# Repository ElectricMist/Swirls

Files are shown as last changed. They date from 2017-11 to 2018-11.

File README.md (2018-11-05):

PCBs and Front panels Available at Pusherman at a fair price :
https://pushermanproductions.com/product/swirls-lamb-8hp-tides-sheep-black-fr4-reversible-panel-pcb-set/

Swirls is a 8HP version of Mutable Instruments Tides

- PCB v1.0 is tested and working
  known issues :
  side holes for the trimmers are too small,
  Silkscreen Mistake (C26 & R27 are flipped)
  
- PCB V1.1 
  the errors of v1.0 are fixed
  
The front panel is double Side
  - One side for Swirls (running the Tides firmware)
  - One side for Lamb (running the Sheep firmware)

Please if you are planning to sell some pcbs and panels, contact me first.

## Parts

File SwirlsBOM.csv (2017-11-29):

SWIRLS V1.0
Index | Qty | Description | Specs | Value | Package | Ref. Mouser | References
SMT parts
R2, R3, R4, R7, R9, R10, R22, R24 | 8 | Resistor, 1% |  | 100 | 0603 | 652-CR0603FX-1000ELF
R27 | 1 | Resistor, 1% |  | 270 | 0603 | 652-CR0603FX-2700ELF
R8 | 1 | Resistor, 1% |  | 2.49k | 0603 | 652-CR0603FX-2491ELF
R60 | 1 | Resistor, 1% |  | 2.49k | 0805 | 652-CR0805FX-2491ELF
R12, R50, R52 | 3 | Resistor, 1% |  | 3.3k | 0603 | 652-CR0603-FX3301ELF
R51, R53 | 2 | Resistor, 1% |  | 4.7k | 0603 | 652-CR0603FX-4701ELF
R47, R48, R49, R57, R58 | 5 | Resistor, 1% |  | 10k | 0603 | 652-CR0603-FX-1002GLF
R34 | 1 | Resistor, 1% |  | 20k | 0603 | 652-CR0603FX-2002ELF
R37 | 1 | Resistor, 1% |  | 27k | 0603 | 652-CR0603FX-2702ELF
R20 | 1 | Resistor, 1% |  | 30k | 0603 | 652-CR0603FX-3002ELF
R13, R15, R28, R33, R40 | 5 | Resistor, 1% |  | 33k | 0603 | 652-CR0603FX-3302ELF
R45 | 1 | Resistor, 1% |  | 39k | 0603 | 652-CR0603FX-3902ELF
R14, R16, R26, R29, R30, R31, R32, R36, R38, R39, R41, R42, R44, R54, R55, R56 | 16 | Resistor, 1% |  | 100k | 0603 | 652-CR0603-FX-1003GLF
R23, R35, R43 | 3 | Resistor, 1% |  | 120k | 0603 | 652-CR0603FX-1203ELF
R21, R25 | 2 | Resistor, 1% |  | 220k | 0603 | 652-CR0603FX-2203ELF
R46 | 1 | Resistor, 1% |  | 3.3M | 0603 | 71-CRCW06033M30FKEA
C2, C17 | 2 | Capacitor, ceramic |  | 18p | 0603 | 81-GRM185C1H180JA01J
C19, C21, C22, C23 | 4 | Capacitor, ceramic | >= 16V, <= 2%, C0G | 220p | 0603 | 81-GRM185C1H221GA01D
C27, C31, C34 | 3 | Capacitor, ceramic | >= 50V, <= 2%, C0G | 1n | 0603 | 81-GRM1885C1H102FA1J
C28, C29, C32 | 3 | Capacitor, ceramic | >= 50V, <= 5% | 10n | 0603 | 81-GRM18R71H103JA01D
C4, C5, C6, C7, C12, C14, C16, C18, C20, C24, C25, C30, C33 | 13 | Capacitor, ceramic | >= 16V | 100n | 0603 | 81-GRM188R71E104JA1J
C13, C26 | 2 | Capacitor, ceramic | >= 16V | 470n | 0603 | 81-GRM18F51C474ZA01J
C11, C15 | 2 | Capacitor, ceramic | >= 6.3V | 3.3u | 0603 | 81-GRM188R61A335KE5D
C1, C8, C9 | 3 | Capacitor, electrolytic | >= 25V | 22u | Panasonic C | 667-EEE-FP1E220AR | EEE-FP1E220AR
C3, C10 | 2 | Capacitor, electrolytic | >= 25V | 47u | Panasonic D | 667-EEE-FK1V470P | EEEFK1V470P
D1, D2 | 2 | 1N5819HW diode |  |  | SOD123 | 621-1N5819HW-F | Diodes Inc 1N5819HW-7-F
IC1, IC3 | 2 | LM1117-3.3V LDO Vreg |  | 3.3V | SO223 | 926-LM1117MPX3.3NOPB | National LM1117MPX3.3NOPB
IC2 | 1 | LM4040 Shunt Vref | A, B or C grade | 2.5V | SOT23 | 595-LM4040C25IDBZR | Texas Instruments LM4040C25IDBZ
IC7 | 1 | LM4040 Shunt Vref | A, B or C grade | 10V | SOT23 | 595-LM4040C10IDBZR | Texas Instruments LM4040C10IDBZ
IC4 | 1 | DAC8552 dual 16-bit DAC |  |  | MSOP8 | 595-DAC8552IDGKT | Texas Instruments DAC8552IDGKT
IC5, IC6 | 2 | TL072 dual op-amp |  |  | TSSOP-8 | 595-TL072CPWR | TI TL072CPWR
IC8 | 1 | MCP6002 dual op-amp R2R IO |  |  | SOIC8 | 579-MCP6002-I/SN | MCP6002-I/SN
IC9 | 1 | MCP6004 dual op-amp R2R IO |  |  | TSSOP-14 | 579-MCP6004-I/ST | MCP6004-I/ST
Q2, Q3, Q4, Q5, Q6 | 5 | NPN transistor MMBT3904 |  |  | SOT23 | 863-MMBT3904LT1G | On Semi MMBT3904LT1G
Q1 | 1 | 8 MHz quartz |  |  | HC49 | 815-ABLS2-8-D4Y-T | Abracon ABLS2-8.000MHZ-D4Y-T
UC1 | 1 | STM32F103CBT6 MCU |  |  | LQFP48 | 511-STM32F103CBT6 | ST STM32F103CBT6
TH parts |  | MFG Part No:D6R90 F1 LFS
J1, J2, J3, J4, J5, J6, J7, J8, J9, J10, J11, J12, J13 | 13 | Vertical jack connector |  |  |  |  | PJ-301-M-12
LED1, LED2, LED3 | 3 | LED, Red/Green, 3 terminals, common K |  |  | 3 terminals | 604-WP115VEGW | Kingbright WP115VEGW
SW3, SW4 | 2 | Push-button 6.0X2.8MM |  |  |  | 612-TL1105SP-250 | E-switch TL1105SPF250Q
 | 2 | Push-button caps |  |  |  | 612-1R-BK | E-switch 1RBLK
R5 | 1 | 10k linear pot, 15mm shaft |  |  |  |  | https://www.thonk.co.uk/shop/alpha-9mm-pots/
R6, R17, R18, R19 | 4 | 10k linear Tall Trimmer |  |  |  |  | https://www.thonk.co.uk/shop/ttpots/
R59 | 1 | 50k Trimmer resistor, 25 turns, top adjust. |  | 50k |  | 652-3296W-1-503LF | 3296W-1-503LF
JP1 | 1 | 2x5 male header, 2.54mm pitch |  |  |  | 649-67996-410HLF
JP2 | 1 | 2x5, 1.27mm pitch male header |  |  |  | 649-221111-00010T4LF

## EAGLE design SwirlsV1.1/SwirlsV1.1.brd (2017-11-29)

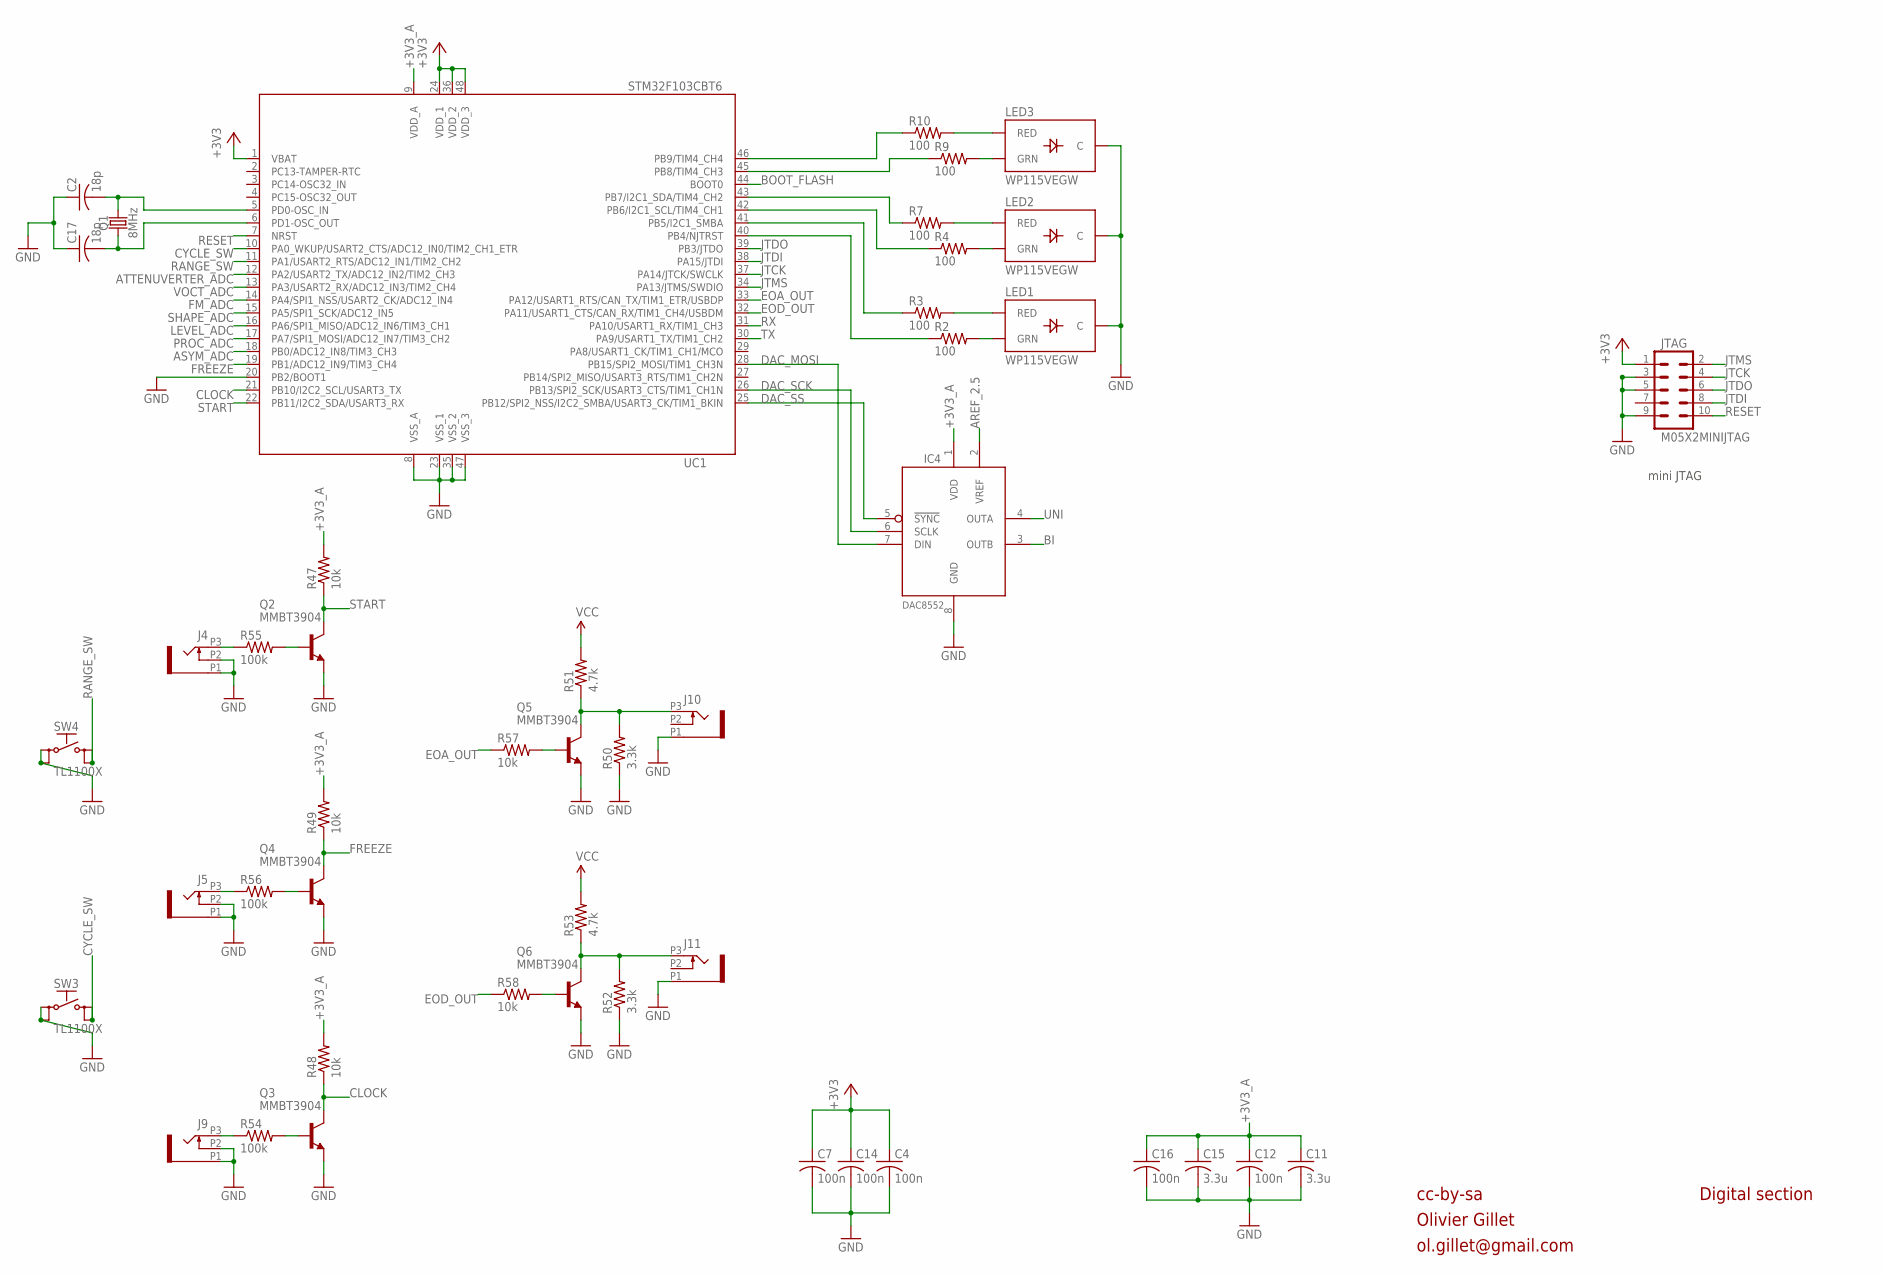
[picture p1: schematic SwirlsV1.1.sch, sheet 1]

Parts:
C2, C17: 18p; C0603
C4, C7, C12, C14, C16: 100n; C0603
C11, C15: 3.3u; C0603
IC4: DAC8552; MSOP-8
J4, J5, J9, J10, J11: PJ301_GUI6; OG-PJ301_VARIATIONS_WQP_PJ_301M6
JTAG: M05X2MINIJTAG; 2X5-1.27
LED1, LED2, LED3: WP115VEGW; LED-BICOLOR-THROUGHHOLE
Q1: 8MHz; HC49UP
Q2, Q3, Q4, Q5, Q6: MMBT3904; SOT23-BEC
R2, R3, R4, R7, R9, R10: 100; R0603
R47, R48, R49, R57, R58: 10k; R0603
R50, R52: 3.3k; R0603
R51, R53: 4.7k; R0603
R54, R55, R56: 100k; R0603
SW3, SW4: TL1100X
UC1: STM32F103CBT6; LQFP48

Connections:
+3V3: C4.1, C7.1, C14.1, JTAG.1, UC1.1 (VBAT), UC1.24 (VDD_1), UC1.36 (VDD_2), UC1.48 (VDD_3); also elsewhere on the board
+3V3_A: C11.1, C12.1, C15.1, C16.1, IC4.1 (VDD), R47.2, R48.2, R49.2, UC1.9 (VDD_A); also elsewhere on the board
AREF_2.5: IC4.2 (VREF); also elsewhere on the board
ASYM_ADC: UC1.18 (PB0/ADC12_IN8/TIM3_CH3); also elsewhere on the board
ATTENUVERTER_ADC: UC1.12 (PA2/USART2_TX/ADC12_IN2/TIM2_CH3); also elsewhere on the board
BI: IC4.3 (OUTB); also elsewhere on the board
BOOT_FLASH: UC1.44 (BOOT0)
CLOCK: Q3.C, R48.1, UC1.21 (PB10/I2C2_SCL/USART3_TX)
CYCLE_SW: SW3.3 (S), SW3.4 (S1), UC1.10 (PA0_WKUP/USART2_CTS/ADC12_IN0/TIM2_CH1_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)
DAC_MOSI: IC4.7 (DIN), UC1.28 (PB15/SPI2_MOSI/TIM1_CH3N)
DAC_SCK: IC4.6 (SCLK), UC1.26 (PB13/SPI2_SCK/USART3_CTS/TIM1_CH1N)
DAC_SS: IC4.5 (!SYNC), UC1.25 (PB12/SPI2_NSS/I2C2_SMBA/USART3_CK/TIM1_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)
EOA_OUT: R57.1, UC1.33 (PA12/USART1_RTS/CAN_TX/TIM1_ETR/USBDP)
EOD_OUT: R58.1, UC1.32 (PA11/USART1_CTS/CAN_RX/TIM1_CH4/USBDM)
FM_ADC: UC1.14 (PA4/SPI1_NSS/USART2_CK/ADC12_IN4); also elsewhere on the board
FREEZE: Q4.C, R49.1, UC1.19 (PB1/ADC12_IN9/TIM3_CH4)
GND: C2.1, C4.2, C7.2, C11.2, C12.2, C14.2, C15.2, C16.2, C17.1, IC4.8 (GND), J4.P1 (1), J4.P2 (2), J5.P1 (1), J5.P2 (2), J9.P1 (1), J9.P2 (2), J10.P1 (1), J11.P1 (1), JTAG.3, JTAG.5, JTAG.9, LED1.2 (C), LED2.2 (C), LED3.2 (C), Q2.E, Q3.E, Q4.E, Q5.E, Q6.E, R50.1, R52.1, SW3.1, SW3.2 (P1), SW4.1, SW4.2 (P1), UC1.8 (VSS_A), UC1.20 (PB2/BOOT1), UC1.23 (VSS_1), UC1.35 (VSS_2), UC1.47 (VSS_3); also elsewhere on the board
JTCK: JTAG.4, UC1.37 (PA14/JTCK/SWCLK)
JTDI: JTAG.8, UC1.38 (PA15/JTDI)
JTDO: JTAG.6, UC1.39 (PB3/JTDO)
JTMS: JTAG.2, UC1.34 (PA13/JTMS/SWDIO)
LEVEL_ADC: UC1.16 (PA6/SPI1_MISO/ADC12_IN6/TIM3_CH1); also elsewhere on the board
unnamed: C2.2, Q1.2, UC1.5 (PD0-OSC_IN)
unnamed: C17.2, Q1.1, UC1.6 (PD1-OSC_OUT)
unnamed: J5.P3 (3), R56.1
unnamed: Q4.B, R56.2
unnamed: J9.P3 (3), R54.1
unnamed: Q3.B, R54.2
unnamed: Q6.B, R58.2
unnamed: J11.P3 (3), Q6.C, R52.2, R53.1
unnamed: LED3.3 (RED), R10.2
unnamed: LED3.1 (GRN), R9.2
unnamed: LED2.3 (RED), R7.2
unnamed: LED2.1 (GRN), R4.2
unnamed: LED1.3 (RED), R3.2
unnamed: LED1.1 (GRN), R2.2
unnamed: R10.1, UC1.46 (PB9/TIM4_CH4)
unnamed: R9.1, UC1.45 (PB8/TIM4_CH3)
unnamed: R7.1, UC1.43 (PB7/I2C1_SDA/TIM4_CH2)
unnamed: R4.1, UC1.42 (PB6/I2C1_SCL/TIM4_CH1)
unnamed: R3.1, UC1.41 (PB5/I2C1_SMBA)
unnamed: R2.1, UC1.40 (PB4/NJTRST)
unnamed: J10.P3 (3), Q5.C, R50.2, R51.1
unnamed: Q5.B, R57.2
unnamed: J4.P3 (3), R55.1
unnamed: Q2.B, R55.2
PROC_ADC: UC1.17 (PA7/SPI1_MOSI/ADC12_IN7/TIM3_CH2); also elsewhere on the board
RANGE_SW: SW4.3 (S), SW4.4 (S1), UC1.11 (PA1/USART2_RTS/ADC12_IN1/TIM2_CH2)
RESET: JTAG.10, UC1.7 (NRST)
RX: UC1.31 (PA10/USART1_RX/TIM1_CH3)
SHAPE_ADC: UC1.15 (PA5/SPI1_SCK/ADC12_IN5); also elsewhere on the board
START: Q2.C, R47.1, UC1.22 (PB11/I2C2_SDA/USART3_RX)
TX: UC1.30 (PA9/USART1_TX/TIM1_CH2)
UNI: IC4.4 (OUTA); also elsewhere on the board
VCC: R51.2, R53.2; also elsewhere on the board
VOCT_ADC: UC1.13 (PA3/USART2_RX/ADC12_IN3/TIM2_CH4); also elsewhere on the board

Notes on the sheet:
cc-by-sa
Olivier Gillet
ol.gillet@gmail.com
Digital section
mini JTAG

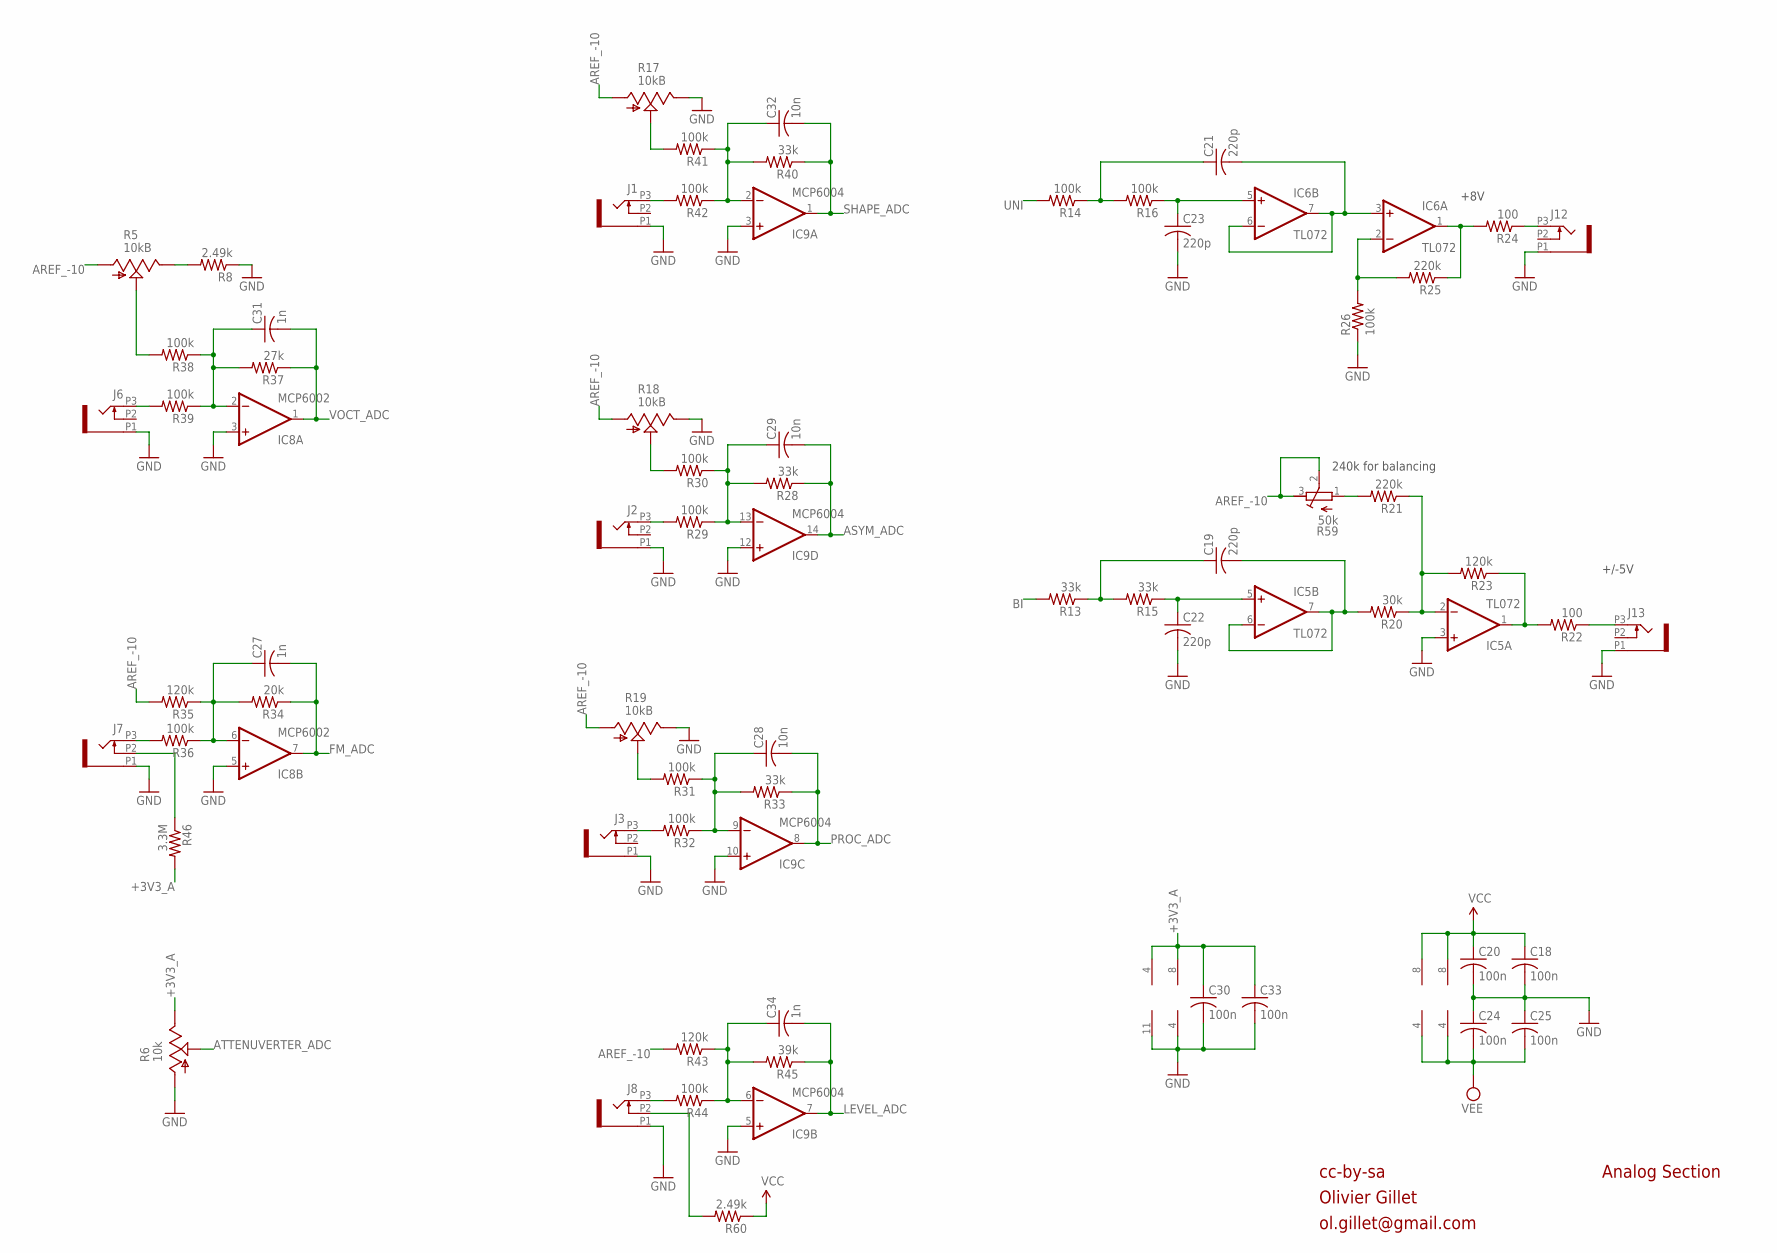
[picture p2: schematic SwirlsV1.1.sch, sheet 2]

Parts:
C18, C20, C24, C25, C30, C33: 100n; C0603
C19, C21, C22, C23: 220p; C0603
C27, C31, C34: 1n; C0603
C28, C29, C32: 10n; C0603
IC5, IC6: TL072; TSSOP-8
IC8: MCP6002; SO08
IC9: MCP6004; TSSOP14
J1, J2, J3, J6, J7, J8, J12, J13: PJ301_GUI6; OG-PJ301_VARIATIONS_WQP_PJ_301M6
R5: 10kB; ALPS_POT_VERTICAL_PS
R6: 10k; TALLTRIMMER
R8: 2.49k; R0603
R13, R15, R28, R33, R40: 33k; R0603
R14, R16, R26, R29, R30, R31, R32, R36, R38, R39, R41, R42, R44: 100k; R0603
R17, R18, R19: 10kB; TALLTRIMMER
R20: 30k; R0603
R21, R25: 220k; R0603
R22, R24: 100; R0603
R23, R35, R43: 120k; R0603
R34: 20k; R0603
R37: 27k; R0603
R45: 39k; R0603
R46: 3.3M; R0603
R59: 50k; RTRIM3296W
R60: 2.49k; R0805

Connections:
+3V3_A: C30.1, C33.1, IC8.8 (V+), IC9.4 (V+), R6.P$1 (E), R46.2; also elsewhere on the board
AREF_-10: R5.P$3 (A), R17.P$3 (A), R18.P$3 (A), R19.P$3 (A), R35.2, R43.2, R59.2 (S), R59.3 (E); also elsewhere on the board
ASYM_ADC: C29.2, IC9.14 (OUT), R28.1; also elsewhere on the board
ATTENUVERTER_ADC: R6.P$2 (S); also elsewhere on the board
BI: R13.2; also elsewhere on the board
BI_OUT: IC5.1 (OUT), R22.2, R23.1
FM_ADC: C27.2, IC8.7 (OUT), R34.1; also elsewhere on the board
F_CV: IC5.2 (-IN), R20.1, R21.1, R23.2
GND: C18.2, C20.2, C22.2, C23.2, C24.1, C25.1, C30.2, C33.2, IC5.3 (+IN), IC8.3 (+IN), IC8.4 (V-), IC8.5 (+IN), IC9.3 (+IN), IC9.5 (+IN), IC9.10 (+IN), IC9.11 (V-), IC9.12 (+IN), J1.P1 (1), J2.P1 (1), J3.P1 (1), J6.P1 (1), J7.P1 (1), J8.P1 (1), J12.P1 (1), J13.P1 (1), R6.P$3 (A), R8.1, R17.P$1 (E), R18.P$1 (E), R19.P$1 (E), R26.1; also elsewhere on the board
LEVEL_ADC: C34.2, IC9.7 (OUT), R45.1; also elsewhere on the board
unnamed: J1.P3 (3), R42.2
unnamed: C32.1, IC9.2 (-IN), R40.2, R41.1, R42.1
unnamed: R17.P$2 (S), R41.2
unnamed: J2.P3 (3), R29.2
unnamed: C29.1, IC9.13 (-IN), R28.2, R29.1, R30.1
unnamed: J7.P2 (2), R46.1
unnamed: R18.P$2 (S), R30.2
unnamed: J3.P3 (3), R32.2
unnamed: C28.1, IC9.9 (-IN), R31.1, R32.1, R33.2
unnamed: R19.P$2 (S), R31.2
unnamed: J8.P3 (3), R44.2
unnamed: C34.1, IC9.6 (-IN), R43.1, R44.1, R45.2
unnamed: J6.P3 (3), R39.2
unnamed: C31.1, IC8.2 (-IN), R37.2, R38.1, R39.1
unnamed: R5.P$2 (S), R38.2
unnamed: J13.P3 (3), R22.1
unnamed: R5.P$1 (E), R8.2
unnamed: J7.P3 (3), R36.2
unnamed: C27.1, IC8.6 (-IN), R34.2, R35.1, R36.1
unnamed: R21.2, R59.1 (A)
unnamed: IC6.2 (-IN), R25.2, R26.2
unnamed: C19.2, IC5.6 (-IN), IC5.7 (OUT), R20.2
unnamed: C22.1, IC5.5 (+IN), R15.1
unnamed: C19.1, R13.1, R15.2
unnamed: IC6.1 (OUT), R24.2, R25.1
unnamed: J8.P2 (2), R60.2
unnamed: C21.2, IC6.3 (+IN), IC6.6 (-IN), IC6.7 (OUT)
unnamed: C23.1, IC6.5 (+IN), R16.1
unnamed: C21.1, R14.1, R16.2
PROC_ADC: C28.2, IC9.8 (OUT), R33.1; also elsewhere on the board
SHAPE_ADC: C32.2, IC9.1 (OUT), R40.1; also elsewhere on the board
UNI: R14.2; also elsewhere on the board
UNI_OUT: J12.P3 (3), R24.1
VCC: C18.1, C20.1, IC5.8 (V+), IC6.8 (V+), R60.1; also elsewhere on the board
VEE: C24.2, C25.2, IC5.4 (V-), IC6.4 (V-); also elsewhere on the board
VOCT_ADC: C31.2, IC8.1 (OUT), R37.1; also elsewhere on the board

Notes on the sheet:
cc-by-sa
Olivier Gillet
ol.gillet@gmail.com
Analog Section
+8V
+/-5V
240k for balancing

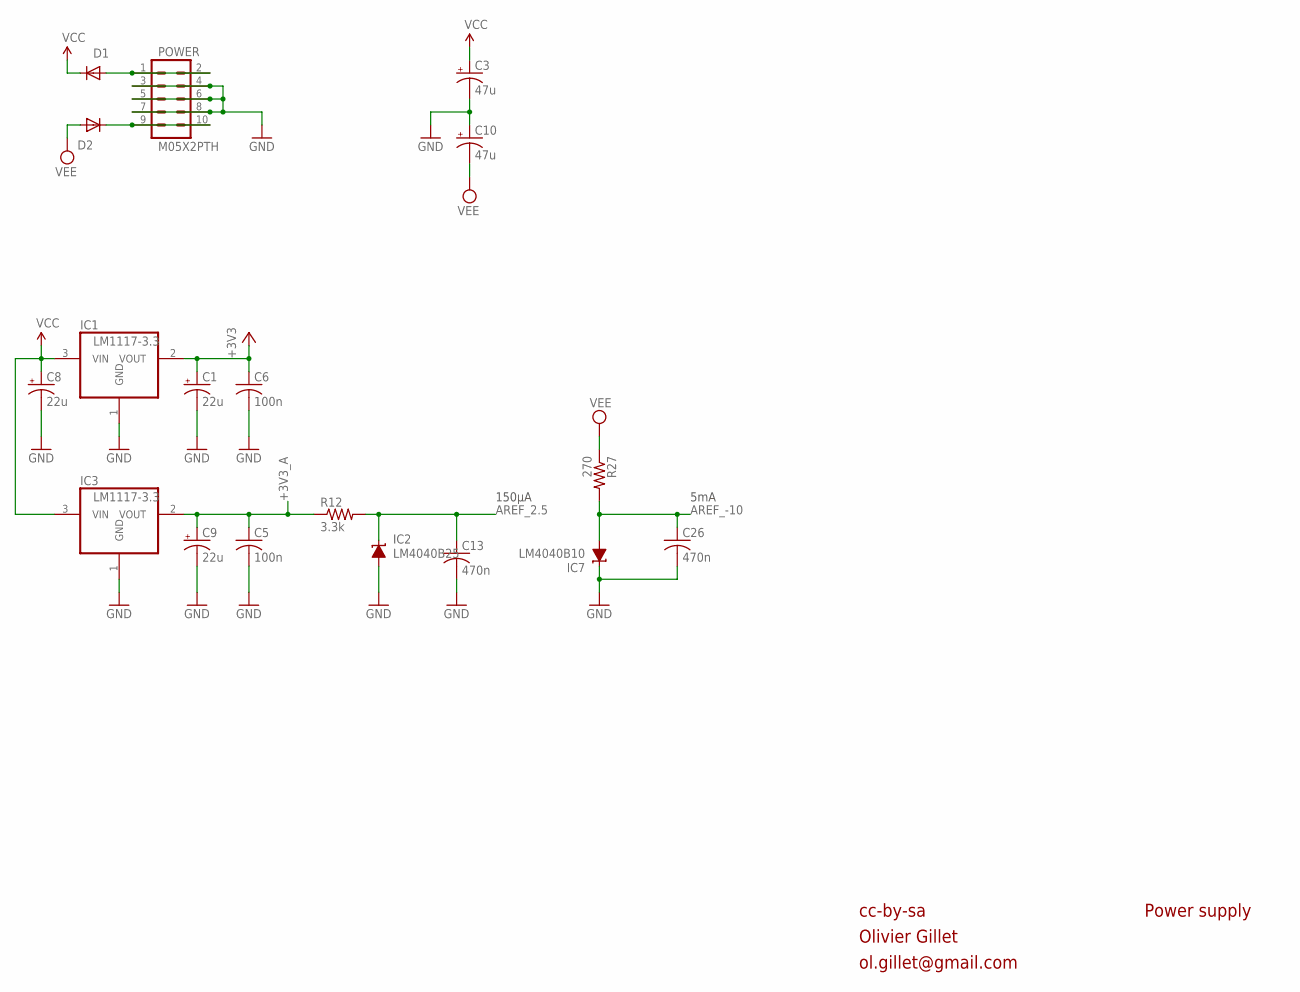
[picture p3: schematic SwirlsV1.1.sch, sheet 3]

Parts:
C1, C8, C9: 22u; PANASONIC_C
C3, C10: 47u; PANASONIC_D
C5, C6: 100n; C0603
C13, C26: 470n; C0603
D1, D2: 1N5819HW; SOD123
IC1, IC3: LM1117-3.3; SOT223
IC2: LM4040B25; DBZ_R-PDSO-G3
IC7: LM4040B10; DBZ_R-PDSO-G3
POWER: M05X2PTH; AVR_ICSP
R12: 3.3k; R0603
R27: 270; R0603

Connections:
+3V3: C1.+, C6.1, IC1.2 (VOUT); also elsewhere on the board
+3V3_A: C5.1, C9.+, IC3.2 (VOUT), R12.1; also elsewhere on the board
AREF_2.5: C13.1, IC2.1 (C), R12.2; also elsewhere on the board
AREF_-10: C26.1, IC7.2 (A), R27.2; also elsewhere on the board
GND: C1.-, C3.-, C5.2, C6.2, C8.-, C9.-, C10.+, C13.2, C26.2, IC1.1 (GND), IC2.2 (A), IC3.1 (GND), IC7.1 (C), POWER.3, POWER.4, POWER.5, POWER.6, POWER.7, POWER.8; also elsewhere on the board
unnamed: D1.A, POWER.1, POWER.2
unnamed: D2.C, POWER.9, POWER.10
VCC: C3.+, C8.+, D1.C, IC1.3 (VIN), IC3.3 (VIN); also elsewhere on the board
VEE: C10.-, D2.A, R27.1; also elsewhere on the board

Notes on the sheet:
cc-by-sa
Olivier Gillet
ol.gillet@gmail.com
Power supply
5mA
150µA

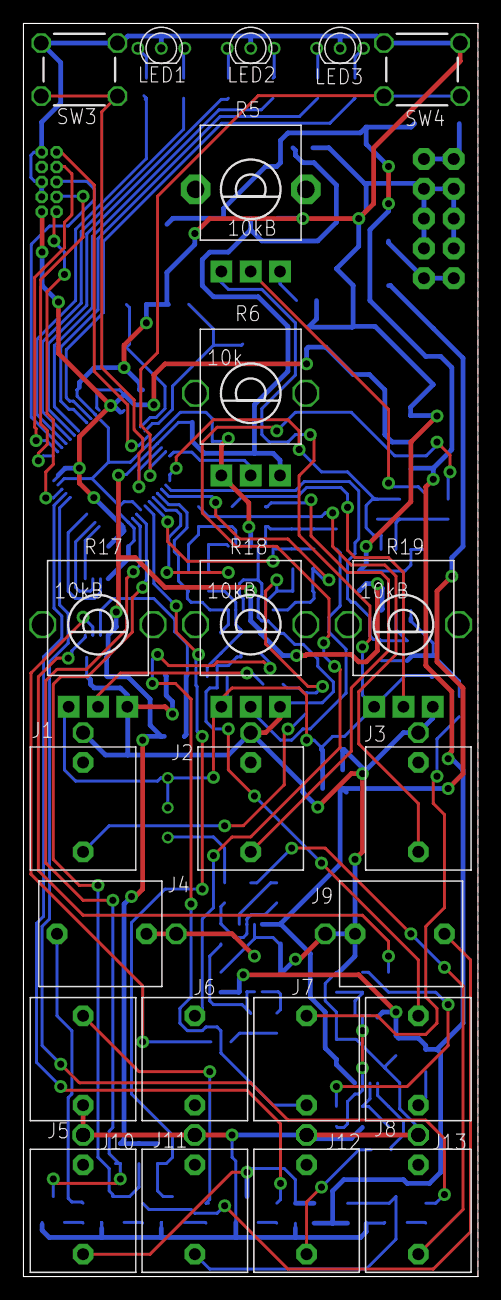
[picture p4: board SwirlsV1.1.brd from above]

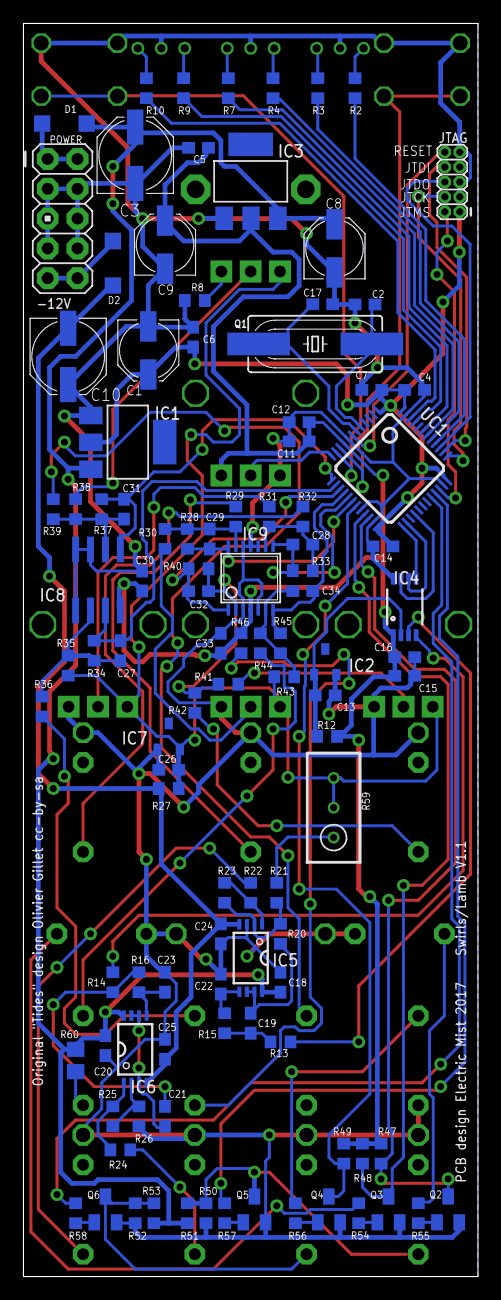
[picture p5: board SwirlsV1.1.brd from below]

Board: 2 copper layers, 38.7 x 106.8 mm, 130 parts (107 on the bottom side), 89 nets.

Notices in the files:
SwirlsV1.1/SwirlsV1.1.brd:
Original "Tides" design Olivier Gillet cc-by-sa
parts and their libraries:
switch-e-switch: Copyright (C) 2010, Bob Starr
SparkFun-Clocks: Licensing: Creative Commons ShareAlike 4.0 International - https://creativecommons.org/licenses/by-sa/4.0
